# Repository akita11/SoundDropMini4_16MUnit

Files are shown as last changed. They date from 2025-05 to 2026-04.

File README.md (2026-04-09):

# SoundDropMini4MUnit

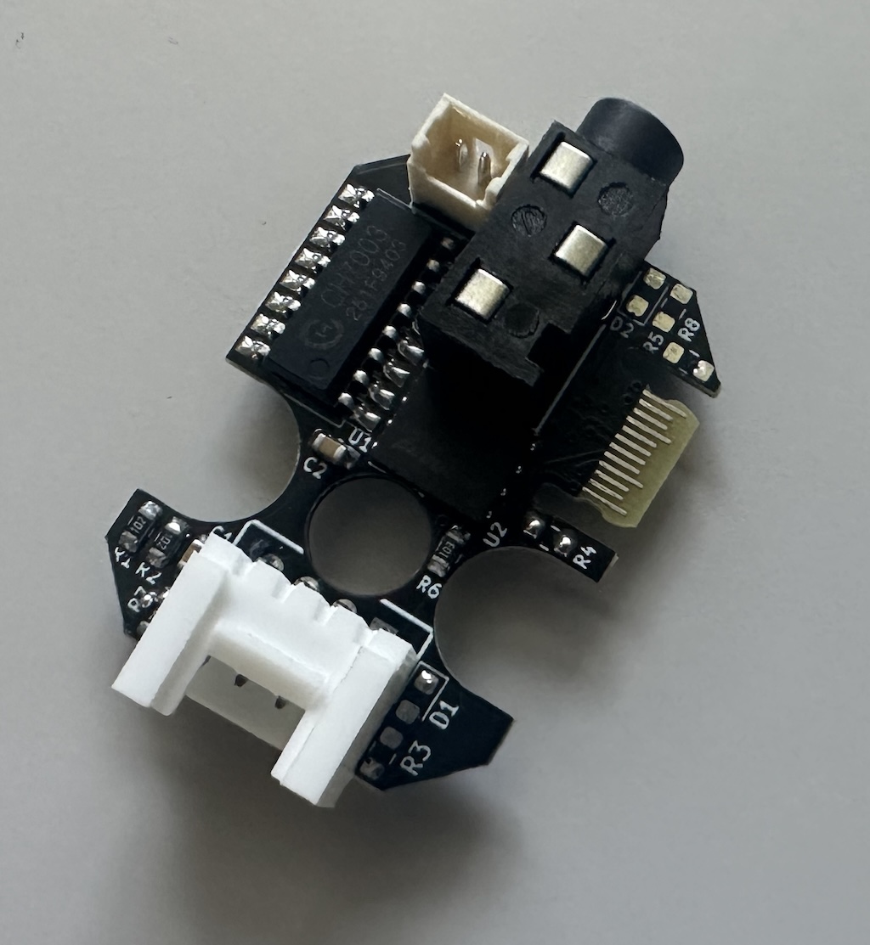
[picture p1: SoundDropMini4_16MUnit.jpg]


音声再生IC CH7003を使用した音声再生モジュールです。4MB（または16MB）のフラッシュメモリを搭載しており、PCにUSB Type-Cケーブルで接続するとUSBメモリとして認識され、そこにMP3音声データ等をコピーします。その音声データをGrove端子のシリアル(UART)通信で再生制御できます。UIFlow(v1)用のブロックもあります。

※CH7003に関する情報は[メーカWebページ](https://www.ch2003.com/h-col-124.html)等で検索してください。要点は以下にまとめてあります。

## 使い方（接続方法）

以下のようにスピーカやアンプを接続し、Grove端子からの制御で音声を再生します。必要に応じて基板裏面の半田ジャンパをショート・カットしてください。

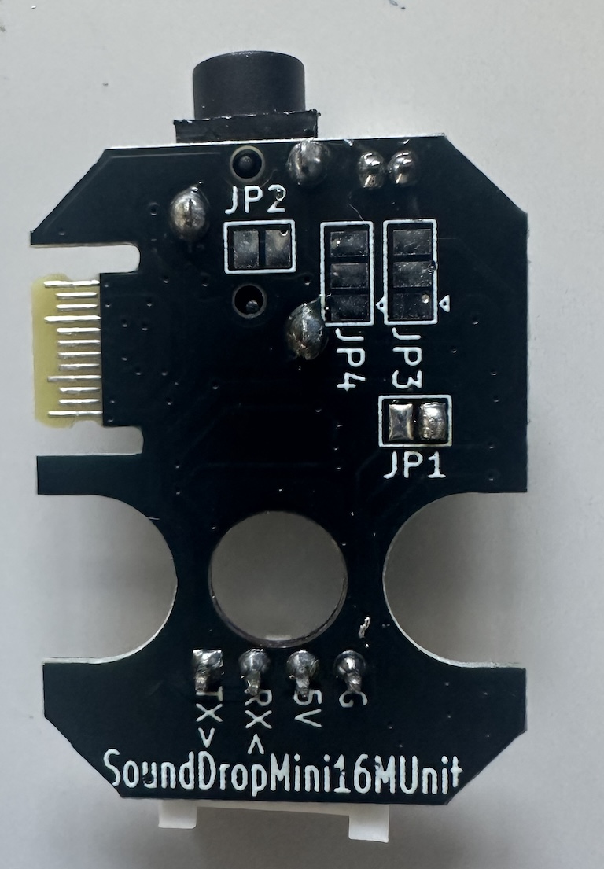
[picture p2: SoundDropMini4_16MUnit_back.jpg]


### アンプ付きスピーカに接続する場合

3.5mmジャック（ステレオ：上部中央）に3.5mmステレオケーブル等でアンプに接続します。
またJP1を半田等でショートしますにします。

### スピーカを直接接続する場合

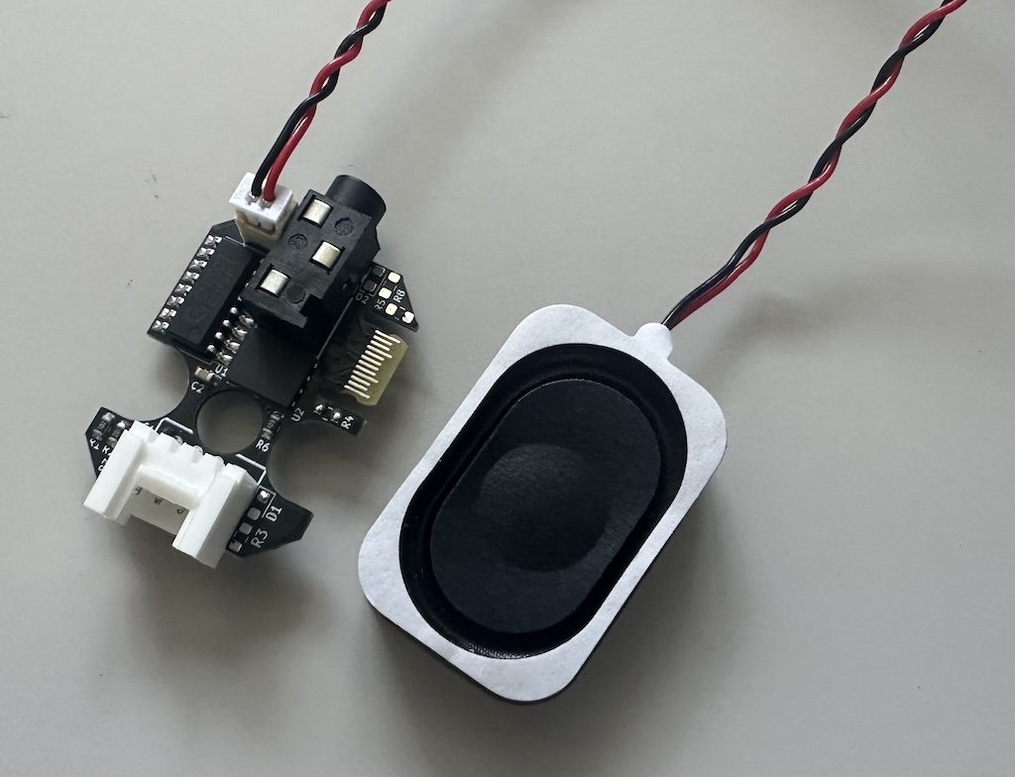
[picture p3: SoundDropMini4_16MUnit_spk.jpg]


基板上部にある1.25mmピッチコネクタ(Molex 53047-0210用)をとりつける端子があり、市販の小型スピーカ（M5Stack本体に使われているものなど。AliExpressやTaobaoでも同等品があります）を接続することができます。※隙間がせまく差し込みにくいので注意してください。
またJP1を開放（初期状態）します。

### 3.5mmジャックに直接スピーカを接続する方法

3.5mmジャックに直接スピーカを接続することもできます。その場合は、基板裏面のハンダジャンパを以下のように修正してください。（スピーカはモノラル再生となります）
※結線は、プラグの根本側から、GND-SPK-NC(無接続)、の順となります。そのため、ステレオ型スピーカではL側からの再生になります。またモノラルプラグでは、このGNDとSPKが短絡されるため使用できません。

- JP2をカット
- JP3・JP4の中央と△マーク側をカットし、中央と反対側（△マークがない側）をショート

## 本体機能の設定

[メーカWebページ](https://www.ch2003.com/h-col-124.html)から"CH7003语音芯片模块.zip"）をダウンロードし、その中にあるテスト用ソフトウエア（Windows用）で、音量などを設定できます。ただし日本語PCでは文字化けするため、データシート中のソフトウエア画面と比べながら使うことになります。なお後述のコマンドでも設定できます。

## 使い方（ソフトウエア）

あらかじめ、本体基板の一部にあるUSB Type-CにUSB Type-Cケーブルを使ってPCへ接続し、現れるドライブに使用する音声データ（*.mp3）をコピーしておきます。なおファイル名は、「"001"から"999"の3桁の数値」のみが有効（CH7003の仕様）となり、その数値が「曲番号」となります。
※mp3のビットレートが高すぎると、正しく再生されない場合があるようです。その場合はビットレートを落として使ってください。

### UIFlow(v1)での使い方

[SoundDropMiniUNIT](https://github.com/akita11/SoundDropMIniUNIT)のページから「SoundDropMini.m5b」をダウンロードし、UIFlow(v1)の"Custom"の"Open *.m5b"からこのファイルを指定すると、Init、Play、Stopの3つのブロックを使用できます。（SoundDropMiniUNITと主な再生関連のコマンドは同一です）

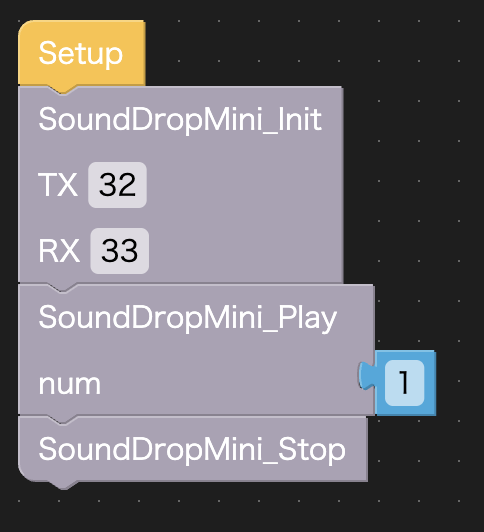
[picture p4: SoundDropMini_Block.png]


- SoundDropMini_Init : 初期化。最初に1回だけ使用します。"TX"と"RX"には、使用するGroveポート・マイコン本体にあわせて、使用するピン番号を指定します。例えば、M5StackBasicのPortA（本体の赤いコネクタ）の場合は、上図のようにTX=21、RX=22を指定します。M5StackCore2のPortAの場合は、TX=32、RX=33となります。
- SoundDropMini_Play : numに指定した「曲番号」の音声を再生します。
- SoundDropMini_Stop : 再生中の音声を停止します。

※この例では再生した直後に停止していますので、音声がほぼ聞こえません。実際には目的に合わせて使い分けてください。

### その他のソフトウエアでの使い方

搭載されている音声再生IC(CH7003)のデータシート等を参考に、制御コマンドをUART経由で送信して使用してください。通信プロトコルは「9600bps/N81」です。
制御コマンドの一部を以下にまとめます。

- 次の曲の再生: 0x7e 0x11 0x00 0x02 0x00 0x00 0xef
- 前の曲の再生: 0x7e 0x12 0x00 0x02 0x00 0x00 0xef
- 指定した曲(HH:LL＝曲番号(上位/下位の順))の再生: 0x7e 0x13 0x00 0x02 HH LL 0xef
- 音量UP: 7e 0x14 0x00 0x02 0x00 0x00 0xef
- 音量DOWN: 0x7e 0x15 0x00 0x02 0x00 0x00 0xef
- 音量をNNに設定: 0x7e 0x16 0x00 0x02 0x00 NN 0xef
- 再生停止: 0x7e 0x26 0x00 0x02 0x00 0x00 0xef

## Author

Junichi Akita (@akita11) / akita@ifdl.jp

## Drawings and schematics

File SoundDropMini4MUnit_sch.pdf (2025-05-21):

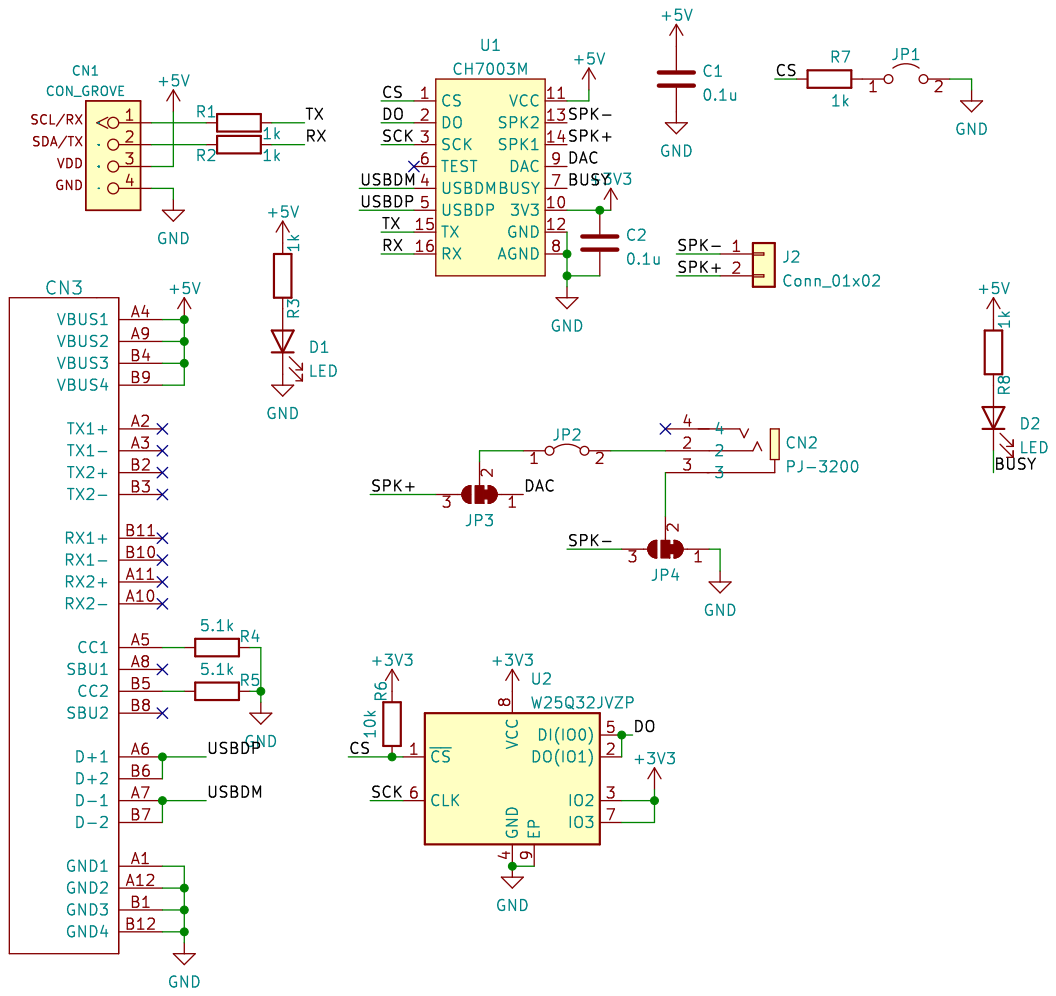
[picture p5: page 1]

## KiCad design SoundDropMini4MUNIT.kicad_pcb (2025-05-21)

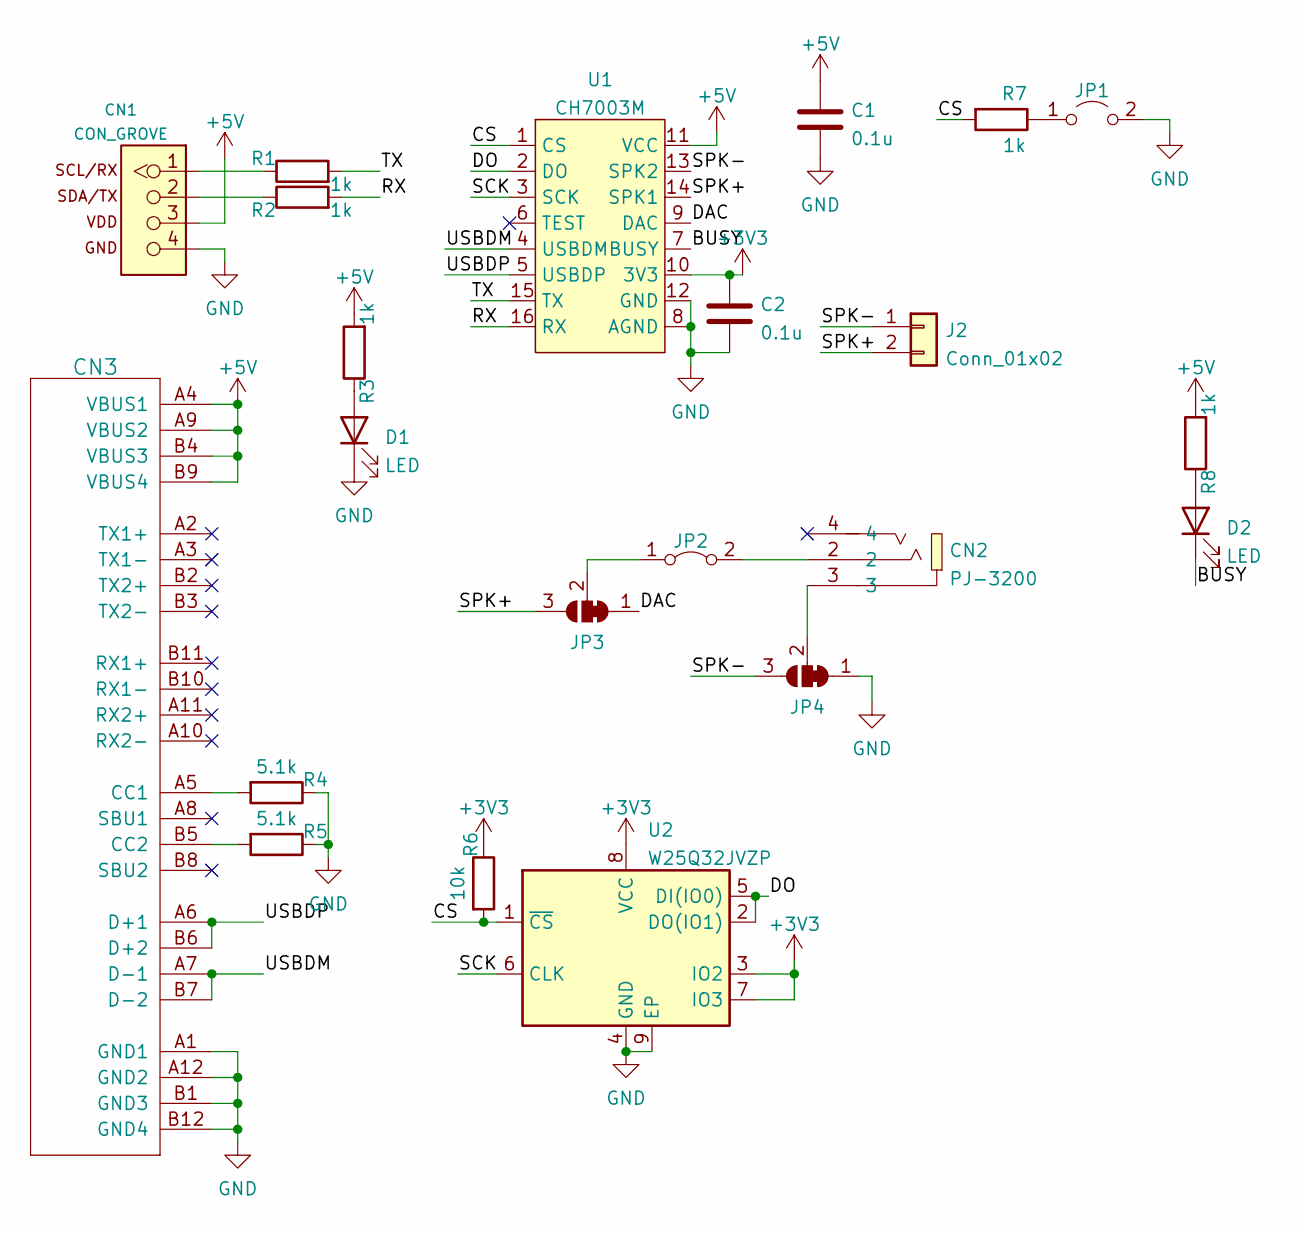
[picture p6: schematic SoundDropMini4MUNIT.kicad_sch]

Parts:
C1, C2: 0.1u; C_0603_1608Metric
CN1: CON_GROVE; CON_GROVE_H
CN2: PJ-3200; AUDIO-TH_PJ-3200; LCSC Part C2689690
CN3: CON_USB-CPCBPLUG; USB-C_PCBPLUG
D1, D2: LED; LED_0603_1608Metric
J2: Conn_01x02; Molex_PicoBlade_53047-0210_1x02_P1.25mm_Vertical
JP1: Jumper_2_Open; SolderJumper-2_P1.3mm_Open_Pad1.0x1.5mm
JP2: Jumper_2_Bridged; SolderJumper-2_P1.3mm_Bridged_Pad1.0x1.5mm
JP3, JP4: SolderJumper_3_Bridged12; SolderJumper-3_P1.3mm_Bridged12_Pad1.0x1.5mm
R1, R2, R3, R7, R8: 1k; R_0603_1608Metric
R4, R5: 5.1k; R_0603_1608Metric
R6: 10k; R_0603_1608Metric
U1: CH7003M; SOP-16_4.4x10.4mm_P1.27mm
U2: W25Q32JVZP; WSON-8-1EP_6x5mm_P1.27mm_EP3.4x4.3mm

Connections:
+3V3: C2.1, R6.1, U1.10 (3V3), U2.3 (IO2), U2.7 (IO3), U2.8 (VCC)
+5V: C1.1, CN1.3, CN3.A4 (VBUS1), CN3.A9 (VBUS2), CN3.B4 (VBUS3), CN3.B9 (VBUS4), R3.2, R8.2, U1.11 (VCC)
/BUSY: D2.1 (K), U1.7 (BUSY)
/CS: R6.2, R7.2, U1.1 (CS), U2.1 (~CS)
/DAC: JP3.1 (A), U1.9 (DAC)
/DO: U1.2 (DO), U2.2 (DO(IO1)), U2.5 (DI(IO0))
/RX: R2.2, U1.16 (RX)
/SCK: U1.3 (SCK), U2.6 (CLK)
/SPK+: J2.2, JP3.3 (B), U1.14 (SPK1)
/SPK-: J2.1, JP4.3 (B), U1.13 (SPK2)
/TX: R1.2, U1.15 (TX)
/USBDM: CN3.A7 (D-1), CN3.B7 (D-2), U1.4 (USBDM)
/USBDP: CN3.A6 (D+1), CN3.B6 (D+2), U1.5 (USBDP)
GND: C1.2, C2.2, CN1.4, CN3.A1 (GND1), CN3.A12 (GND2), CN3.B1 (GND3), CN3.B12 (GND4), D1.1 (K), JP1.2 (B), JP4.1 (A), R4.1, R5.1, U1.8 (AGND), U1.12 (GND), U2.4 (GND), U2.9 (EP)
unnamed: CN1.1, R1.1
unnamed: CN1.2, R2.1
unnamed: CN2.2, JP2.2 (B)
unnamed: CN2.3, JP4.2 (C)
unnamed: CN3.A5 (CC1), R4.2
unnamed: CN3.B5 (CC2), R5.2
unnamed: D1.2 (A), R3.1
unnamed: D2.2 (A), R8.1
unnamed: JP1.1 (A), R7.1
unnamed: JP2.1 (A), JP3.2 (C)

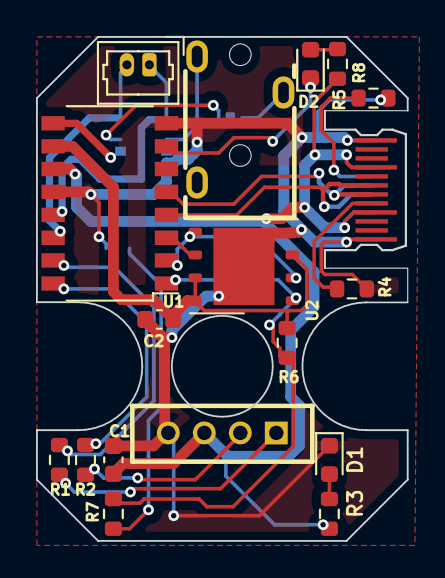
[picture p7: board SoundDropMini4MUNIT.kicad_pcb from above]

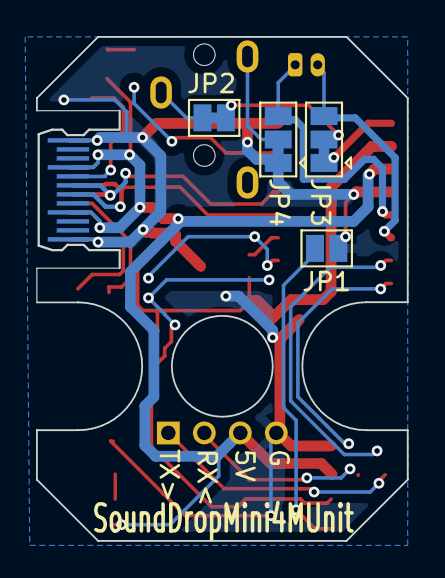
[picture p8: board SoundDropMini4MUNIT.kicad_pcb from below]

Board: 2 copper layers, 20.6 x 28.0 mm, 22 parts (4 on the bottom side), 24 nets.

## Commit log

2025-05-21 initial commit, no photo
    [SoundDropMini4MUNIT.kicad_pcb, SoundDropMini4MUNIT.kicad_sch]
2026-04-09 Update README with speaker connection instructions
    Added instructions for connecting speakers directly to the 3.5mm jack, including jumper modifications.
